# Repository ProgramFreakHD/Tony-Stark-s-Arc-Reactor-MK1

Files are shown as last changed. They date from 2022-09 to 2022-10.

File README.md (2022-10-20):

# Tony Stark's Arc Reactor MK1



## Description

READ THIS!

This Arc reactor was design in Fusion 360 under the free license, The Autodesk team has stated that "non-commercial use" meaning no one is allowed to sell or manufature the Arc reactor for profit!

DO NOT SEND ME ANY MESSAGE ABOUT PERSMISSION TO USE MY DESIGN FOR COMMERCIAL USE!

I have no controll over what will happen if failed to follow the terms, I did my end of the agreement by stating the obvious, if the end user fails to follow these terms, you will be hold accountable!

If you like my work and would like to show appreciation then consider leaving a Tip. Thank you! [PaypalMe](https://www.paypal.com/paypalme/ProgramFreakHD9999)

====================================================================

Recreated Tony Stark's arc reactor from Iron Man 1 (2008) movie. Hope you enjoy it :)

## Links

[Thingiverse Repo](https://www.thingiverse.com/thing:5526410)\
[Yr3design Arc Reactor On Thingiverse](https://www.thingiverse.com/thing:2854850)

## Summary

After looking at so many designs by many people on thingiverse, I couldn't find anything worth printing, so I decided to design my own as I imagined. My design is a bit complicated and requires stady hands, accuracy and patience to make, but it was all worth it at the end. This repository includes everything you need to make your own arc reactor and a list of components you need.

## Print Settings

[Click here for the print setting.](https://github.com/ProgramFreakHD/Ark-reactor/blob/main/Configs/Print%20Settings.md)

## My Print Choice

I decided to print mine in PLA, mainly because it's cheaper and easy to print, and doesn't have a big risk of warpage if you print without a heat chamber. For my arc reactor I decided to use black, transparent & metallic gold PLA. You need transparent PLA or any other transparent filament to be able to make the glow rings, and you need gold filament to print the gold ring in the center of the arc reactor.

Take a look in infill & resolution settings chart underneath to see what parts have to be printed in what filament color.

## Infill & Resolution Settings

The infill & resolution settings I used for my arc reactor varies from parts to parts, most likely 20% infill, but for some parts it had to be 100%. I privided a chart for the print settings and resolution that I used, so that it will make it more easier for you to get you started printing.

[Click here for the infill & resolution settings.](https://github.com/ProgramFreakHD/Ark-reactor/blob/main/Configs/Infill%20%26%20Resolution%20Settings.md)

## Assembling Of Arc Reactor

To assemble the arc reactor there isn't an easy way of describing it, for some people it's a walk in the park and for some others it's mind baffling, I will tell you this, you need good level of soldiering skills, precision and accuracy to asseble it beacuse it requires you to solder near plastic parts, and if you're not careful, you will end up with melt marks in the arc reactor.

**(NOTE: SUPERGLUE OR ANY KIND OF BONDING COMPOUND ARE NOT ALLOWED DURING ASSEMBLY OF ARK REACTOR! ONLY SCREWS ARE MEANT TO BE USED DURING ASSEMBLING!)**

Check out Assembly page to get some idea on how it's assembled. [Click Here](https://github.com/ProgramFreakHD/Tony-Stark-Arc-Reactor-MK1/blob/main/Configs/Assembly.md)

## Parts List

[Click here for the parts list.](https://github.com/ProgramFreakHD/Ark-reactor/blob/main/Configs/Parts%20list.md)

## Images


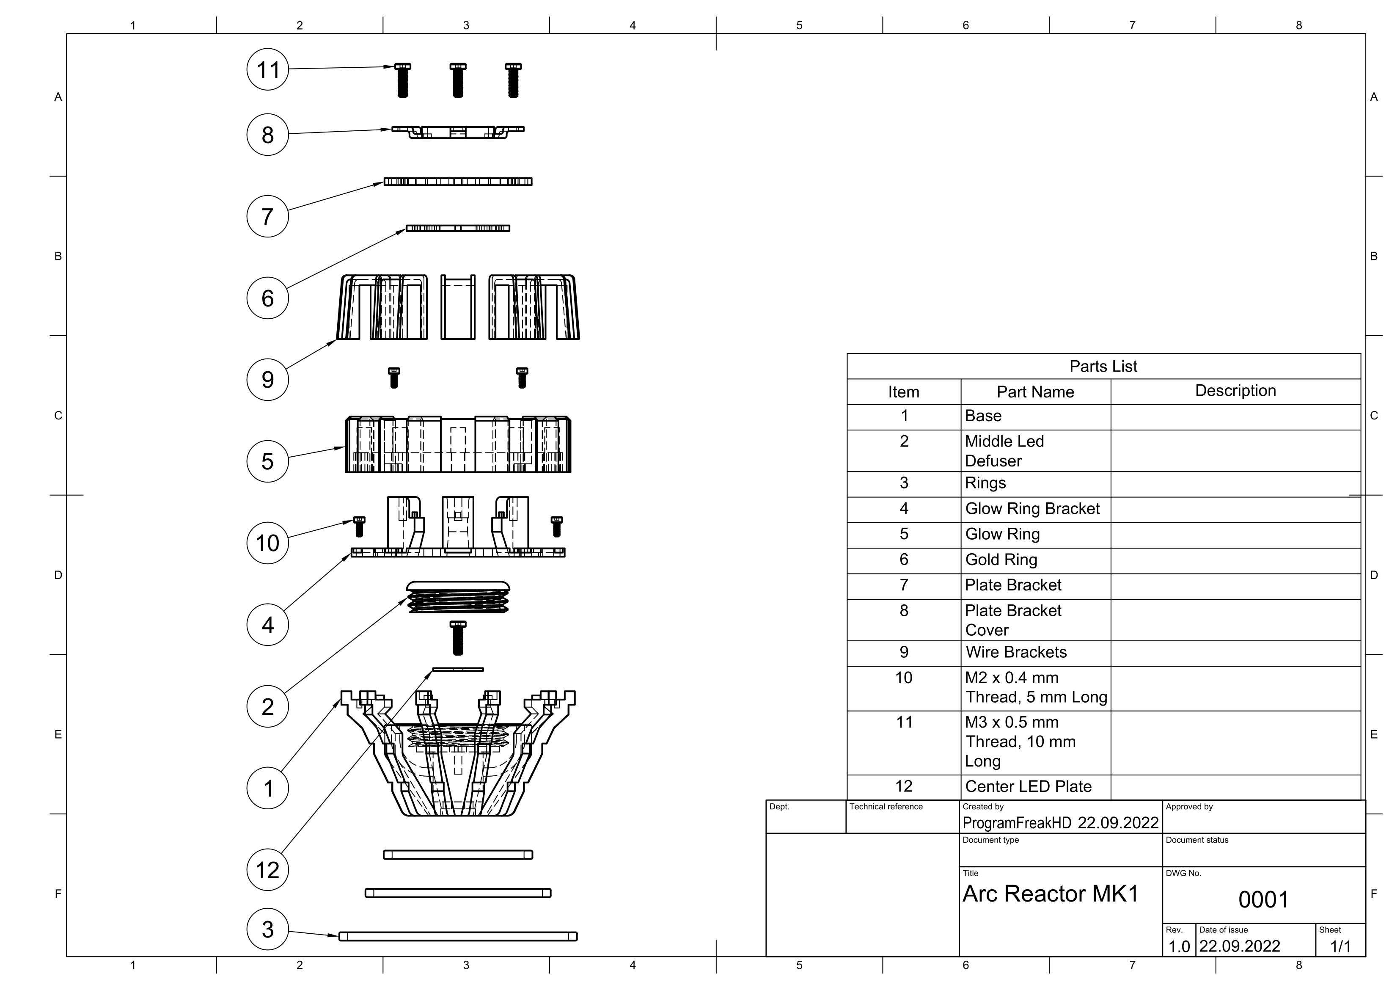
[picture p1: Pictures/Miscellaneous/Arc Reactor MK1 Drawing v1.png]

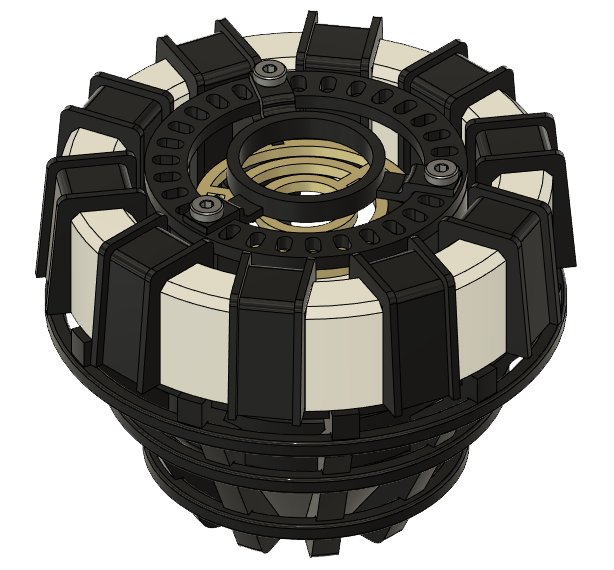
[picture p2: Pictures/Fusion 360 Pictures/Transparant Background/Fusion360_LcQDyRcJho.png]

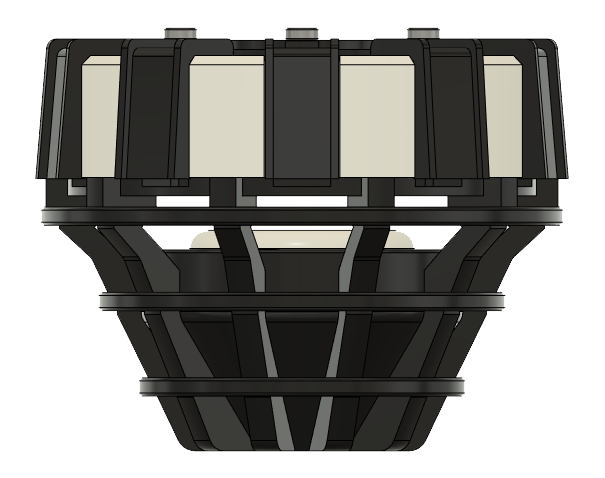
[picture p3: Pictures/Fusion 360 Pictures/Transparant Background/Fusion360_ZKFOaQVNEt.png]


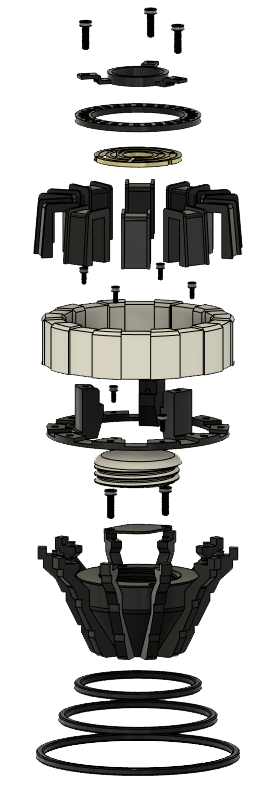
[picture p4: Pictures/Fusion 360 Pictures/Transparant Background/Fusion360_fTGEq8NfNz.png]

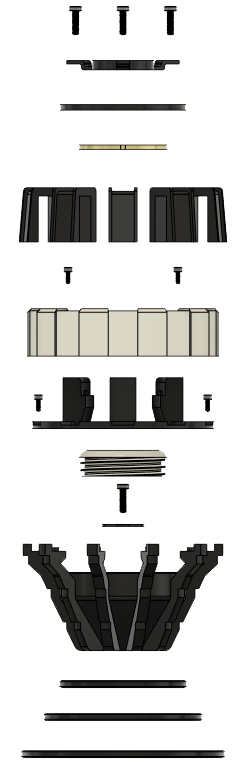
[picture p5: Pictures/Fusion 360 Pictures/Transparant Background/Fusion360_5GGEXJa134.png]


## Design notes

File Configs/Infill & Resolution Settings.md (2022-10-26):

NOTE: This chart is calibrated and designed for the Prusa I3 family printer with a standard E3D 0.4mm nozzl, The Prusa I3 family have a print resolution of minimum 0.05mm, up to a large number that is dependent on your material of choice.

Large amount of simple hobbyist own and use printers that is in Creality family, depending on your printer model and other factors, can vary your layer heigh significantly.

<table>
    <tr>
    <th>Part Names</th>
    <th>Print settings</th>
    <th>Support on build plate only</th>
    <th>Vertical shells perimeters</th>
    <th>Infill pattern</th>
    <th>Infill</th>
    <th>Brim</th>
    <th>Material</th>
    <th>Quantity</th>
  </tr>
    <tr>
    <th>Base</th>
    <th>0.15mm QUALITY</th>
    <th>Yes</th>
    <th>3</th>
    <th>Grid</th>
    <th>20%</th>
    <th>None</th>
    <th>Black PLA</th>
    <th>1</th>
  </tr>
    <tr>
    <th>Middle Led Defuser</th>
    <th>0.15mm QUALITY</th>
    <th>None</th>
    <th>3</th>
    <th>Grid</th>
    <th>100%</th>
    <th>None</th>
    <th>Transparent PLA</th>
    <th>1</th>
  </tr>
    <tr>
    <th>Small, medium and large Rings</th>
    <th>0.15mm QUALITY</th>
    <th>None</th>
    <th>3</th>
    <th>Grid</th>
    <th>100%</th>
    <th>None</th>
    <th>Black PLA</th>
    <th>1</th>
  </tr>
    <tr>
    <th>Glow Ring Bracket</th>
    <th>0.15mm QUALITY</th>
    <th>None</th>
    <th>3</th>
    <th>Grid</th>
    <th>20%</th>
    <th>None</th>
    <th>Black PLA</th>
    <th>1</th>
  </tr>
    <tr>
    <th>Glow Ring</th>
    <th>0.15mm QUALITY</th>
    <th>None</th>
    <th>3</th>
    <th>Grid</th>
    <th>100%</th>
    <th>None</th>
    <th>Transparent PLA</th>
    <th>1</th>
  </tr>
    <tr>
    <th>Gold Ring</th>
    <th>0.15mm QUALITY</th>
    <th>None</th>
    <th>3</th>
    <th>Grid</th>
    <th>100%</th>
    <th>None</th>
    <th>Gold PLA</th>
    <th>1</th>
  </tr>
    <tr>
    <th>Plate Bracket</th>
    <th>0.15mm QUALITY</th>
    <th>None</th>
    <th>3</th>
    <th>Grid</th>
    <th>100%</th>
    <th>None</th>
    <th>Black PLA</th>
    <th>1</th>
  </tr>
    <tr>
    <th>Plate Bracket Cover</th>
    <th>0.15mm QUALITY</th>
    <th>None</th>
    <th>3</th>
    <th>Grid</th>
    <th>100%</th>
    <th>None</th>
    <th>Black PLA</th>
    <th>1</th>
  </tr>
    <tr>
    <th>Wire Brackets</th>
    <th>0.30mm Draft</th>
    <th>Yes</th>
    <th>3</th>
    <th>Grid</th>
    <th>100%</th>
    <th>None</th>
    <th>Black PLA</th>
    <th>10</th>
  </tr>
    <tr>
    <th>Center Led Plate</th>
    <th>0.30mm Draft</th>
    <th>None</th>
    <th>3</th>
    <th>Grid</th>
    <th>100%</th>
    <th>None</th>
    <th>Black PLA</th>
    <th>1</th>
  </tr>
</table>

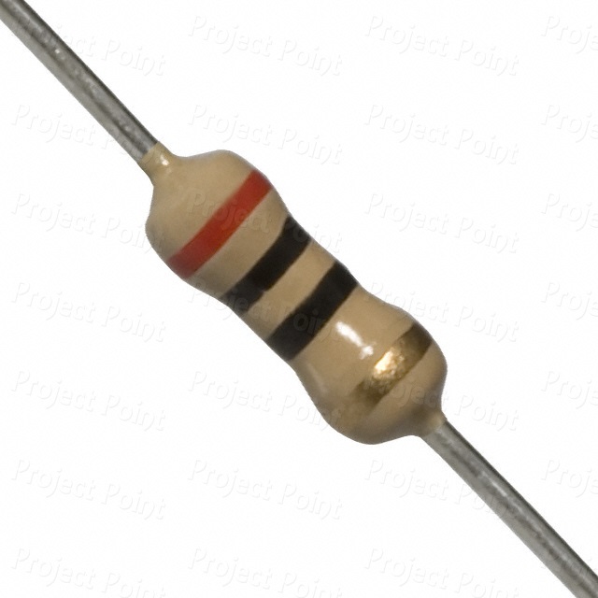
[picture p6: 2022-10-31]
Pictures/Miscellaneous/CFR-25JB-20R-1280x720.jpg

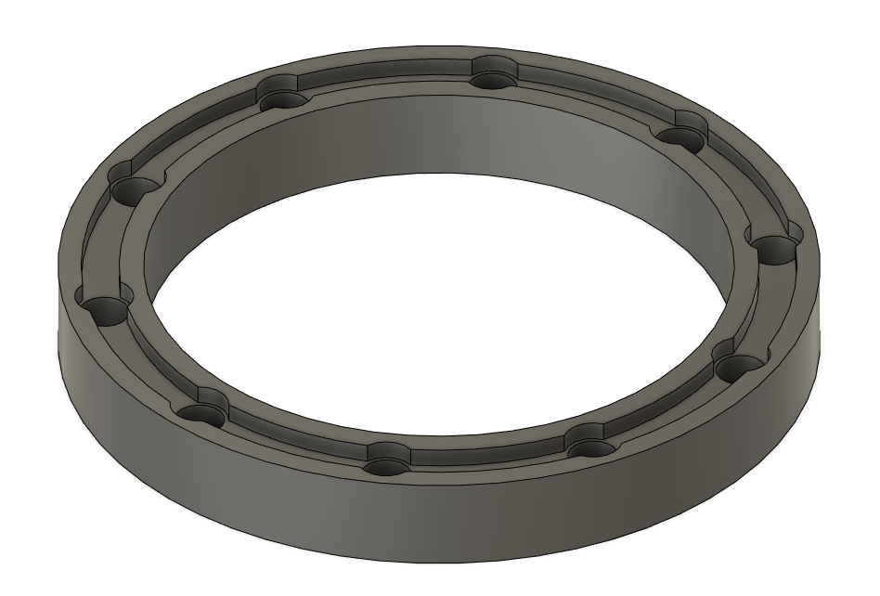
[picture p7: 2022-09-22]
Pictures/Fusion 360 Pictures/White Background/NVIDIA_Share_iF2AldNYLl.png

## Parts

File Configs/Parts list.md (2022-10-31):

## Note, I have not included any direct link for eBay and AliExpress stores, I did that intentionally because some stores do not survive for long!

# Screws

<table>
    <tr>
    <th>Screw types</th>
    <th>Quantity</th>
  </tr>
    <tr>
    <th>M2 x 5mm x 0.4mm</th>
    <th>6</th>
   <tr>
    <th>M3 x 10mm x 0.5mm</th>
    <th>5</th>
</table>

## M2 x 0.4mm Thread, 5mm Long
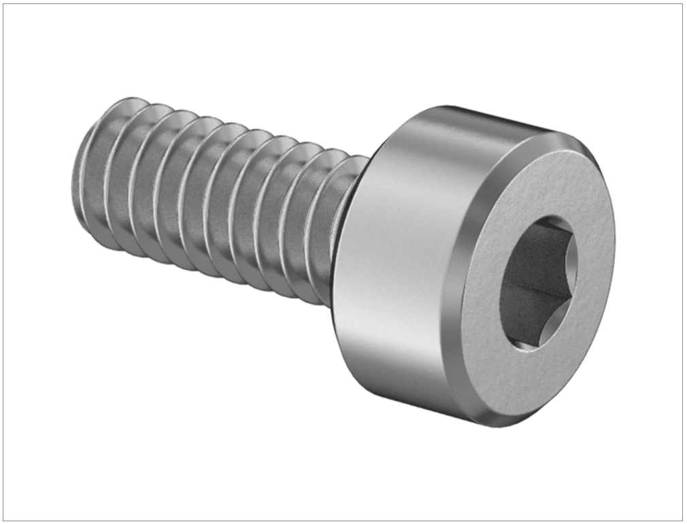
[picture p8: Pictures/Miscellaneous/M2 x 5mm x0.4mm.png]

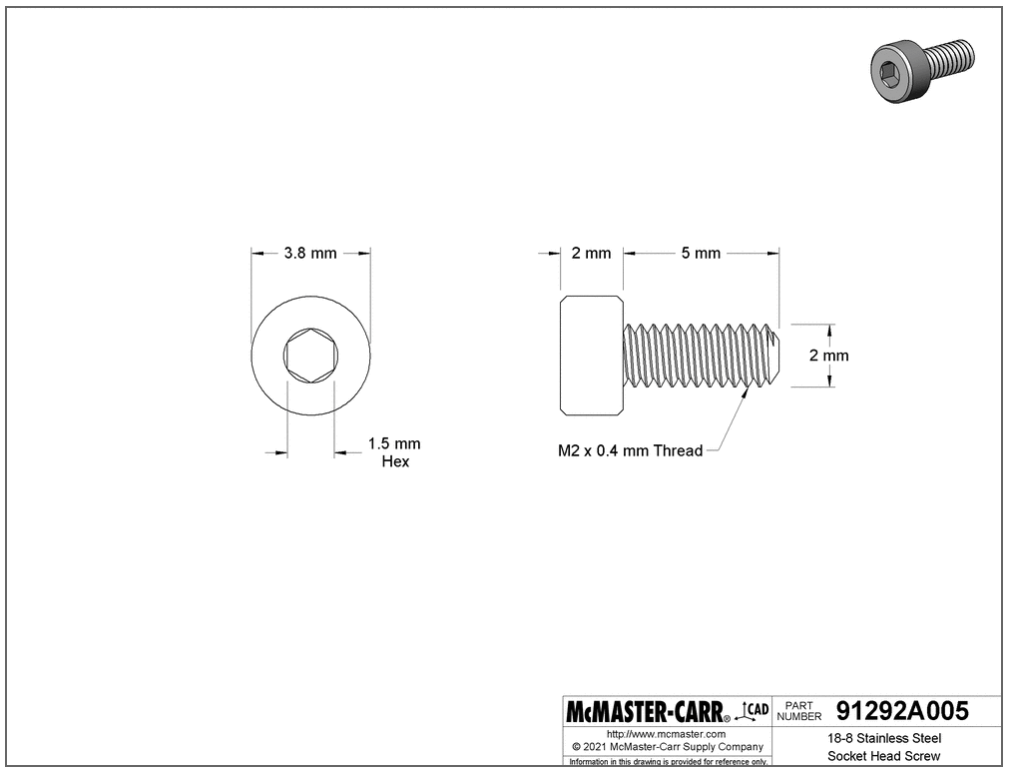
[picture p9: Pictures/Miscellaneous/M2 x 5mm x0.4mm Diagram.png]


## M3 x 0.5mm Thread, 10mm Long
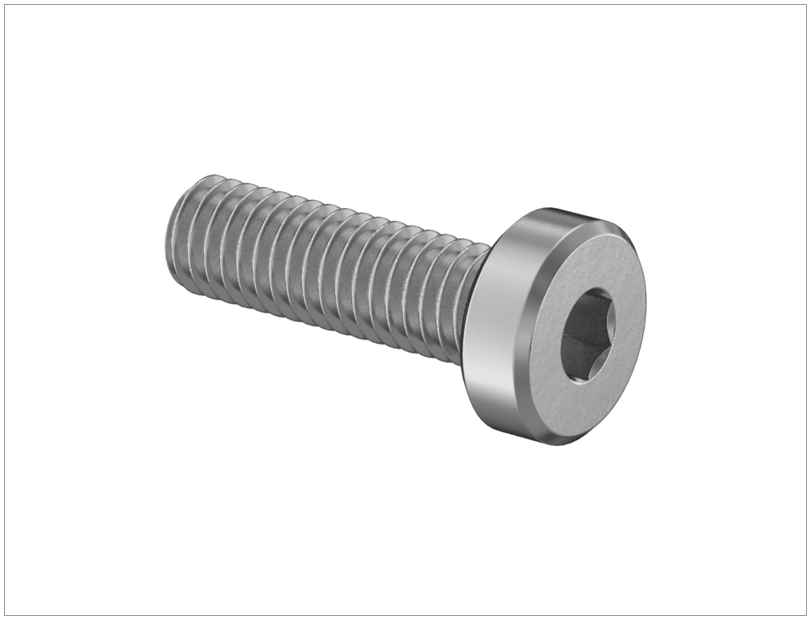
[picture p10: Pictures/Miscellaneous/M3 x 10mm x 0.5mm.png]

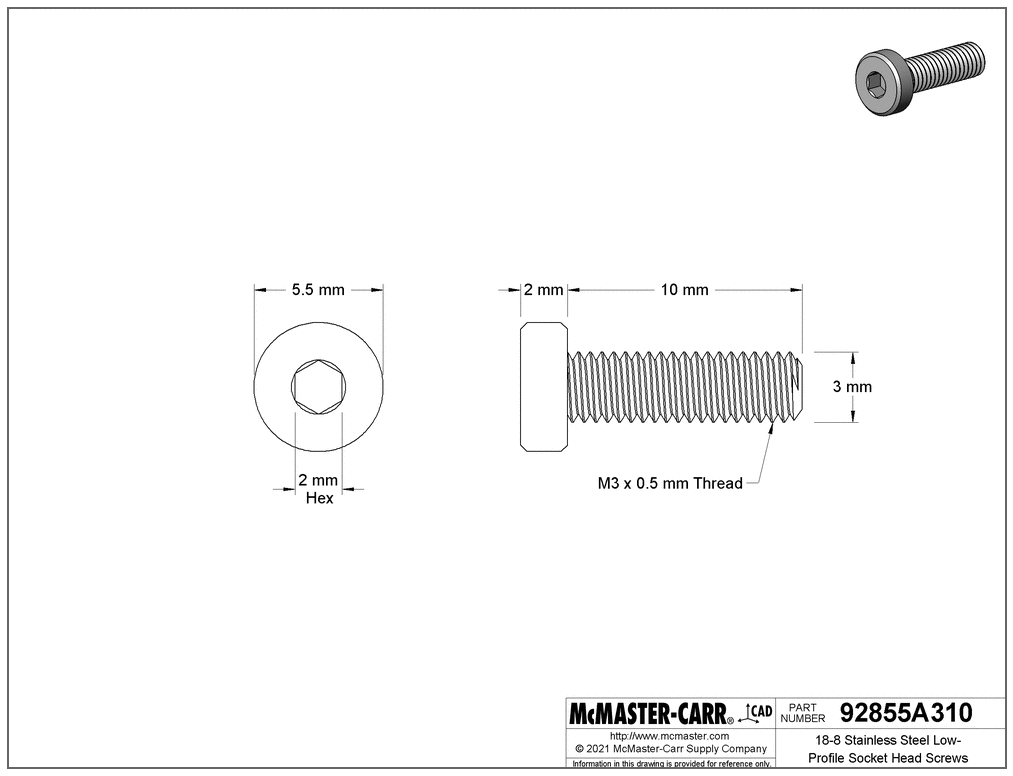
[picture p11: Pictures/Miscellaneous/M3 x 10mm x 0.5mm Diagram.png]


# Components

<table>
    <tr>
    <th>Screw types</th>
    <th>Quantity</th>
  </tr>
    <tr>
    <th>2.1mm x 5.5mm Female DC Jack</th>
    <th>1</th>
   <tr>
    <th>5mm White LED Diodes</th>
    <th>10</th>
   <tr>
    <th>3.3V Star PCB LED</th>
    <th>1</th>
</table>

## 2.1mm x 5.5mm Female DC Jack

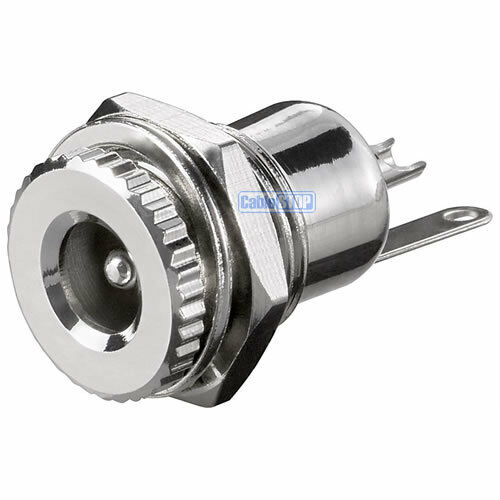
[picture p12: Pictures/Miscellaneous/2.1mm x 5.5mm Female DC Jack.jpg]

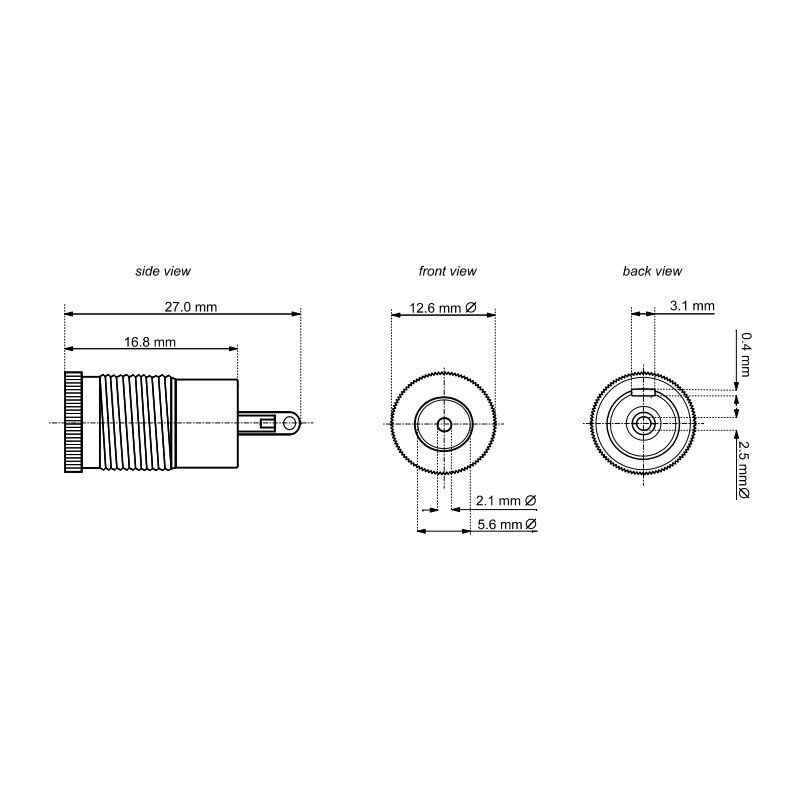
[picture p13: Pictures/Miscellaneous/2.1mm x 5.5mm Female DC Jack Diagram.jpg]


## 5mm White LED Diodes

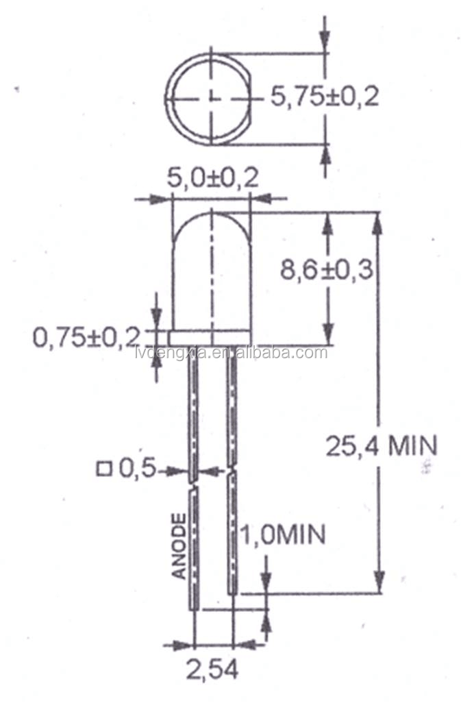
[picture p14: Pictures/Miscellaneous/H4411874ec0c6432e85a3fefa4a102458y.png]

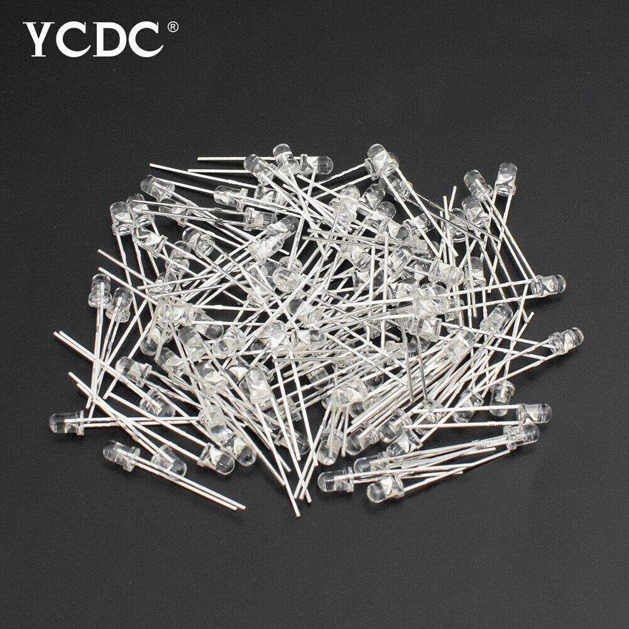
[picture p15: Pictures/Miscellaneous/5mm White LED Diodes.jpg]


## 3.3V Star PCB LED



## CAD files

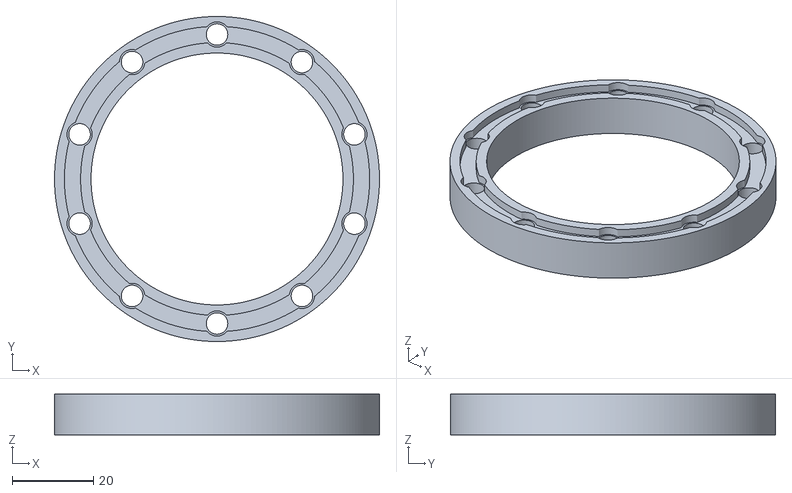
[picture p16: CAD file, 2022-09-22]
Led jig/Arc_Reactor_MK1_LED_Ring_Jig.stl
80.0 x 80.0 x 10.0

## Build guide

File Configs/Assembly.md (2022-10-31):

# LED's assembly for the glow ring.

## Soldering of the glow ring

The glow ring requires 10 white LED's soldered in a circular ring shape, The 10 LED's have to be soldered in parallel config, meaning plus is soldered to plus and minus is soldered to minus all around the ring, that way a 3.3V supply can power them all.

Now for some and many, it might be dificult to solder 10 leds in a circle by freehanding it, well, not wo worry, I have included a jig for you to print and use, it allows you to mount the LED's in a upright possiston for a better and easy solder job, and also allows you to solder them in a circular ring shape.

The jig can be found [Here](https://github.com/ProgramFreakHD/Tony-Stark-s-Arc-Reactor-MK1/tree/main/Led%20jig)!


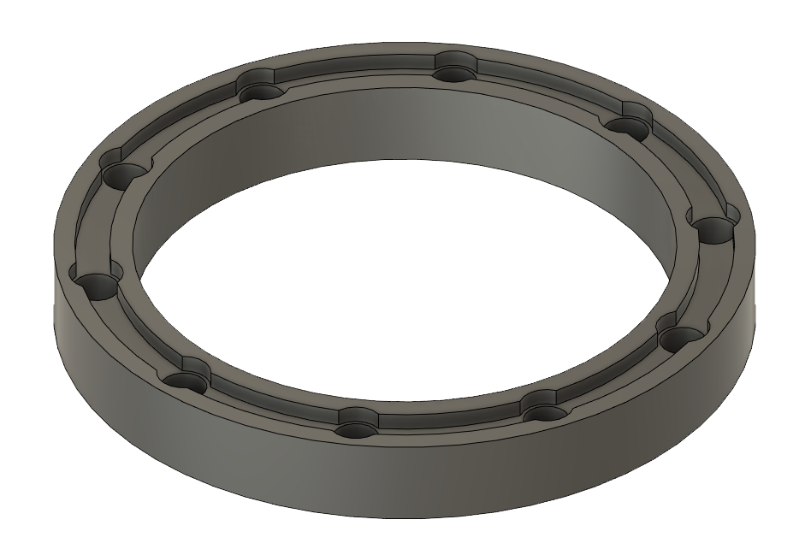
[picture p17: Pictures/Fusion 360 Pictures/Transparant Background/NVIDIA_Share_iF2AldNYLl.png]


## Center LED

The LED I used for the center of the arc reactor is a 3.3V cool white (6500k) star shaped PCB LED, nothing special with the way it's mounted, I have included a center LED plate in the thingiverse repo for you to print and mount the star led on.

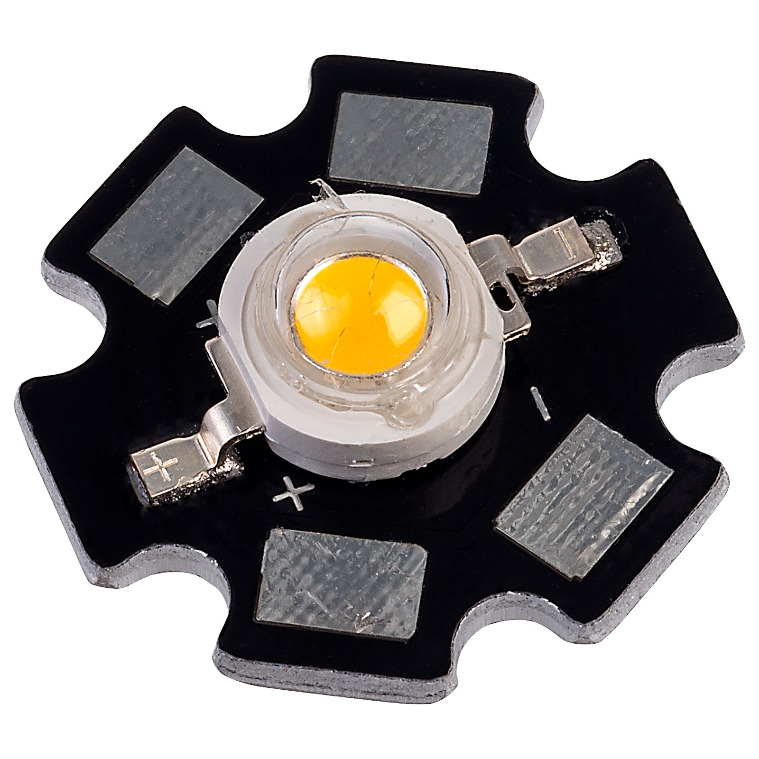
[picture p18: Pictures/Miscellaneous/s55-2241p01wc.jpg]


# Wire wrap and mounting

Insert the Led ring you just finished soldering into the transparent glow ring print, from there, you need the 10pcs wire brackets and some enameled copper wire. Don't forget to solder a pair of enameled copper wire to the led ring to provide power to the ring.

To obtain the enameled copper wire, you can find meters worth of copper wires in some old transformers, or just buy some enameled copper wire from the web.

To keep the copper wire from unwinding itself after a wrap, the best and easiest way I found is to scrape the enameling of the wire and solder the wires together for a secure fixturing.




# Power supply for the LED's

To power the LED's a 3.3V power source is required for the LED's, for my arc reactor I used 20 to 40 ohm resistor to drop down the power start with 20 ohms resistor and work yourself upwards, you can use a 3.3v powered led as a referance point as to what it sould look like, also make sure you test out the resistor on a spare led so you don't accidentally fry the main arc reactor LEDs.

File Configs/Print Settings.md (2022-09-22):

<table>
  <tr>
    <th>Printer brand</th>
    <th>Prusa</th>
  </tr>
    <tr>
    <th>Printer</th>
    <th>I3 MK3S</th>
  </tr>
    <tr>
    <th>Rafts</th>
    <th>No</th>
  </tr>
    <tr>
    <th>Supports</th>
    <th>Yes</th>
  </tr>
    <tr>
    <th>Resolution</th>
    <th>Read the description</th>
  </tr>
    <tr>
    <th>Infill</th>
    <th>Read the description</th>
  </tr>
   <tr>
   <th>Filament brand</th>
   <th>Your choice</th>
  </tr>
    <tr>
    <th>Filament color</th>
    <th>Black, Transparent & Metallic Gold</th>
  </tr>
    <tr>
    <th>Filament material</th>
    <th>PLA</th>
  </tr>
</table>

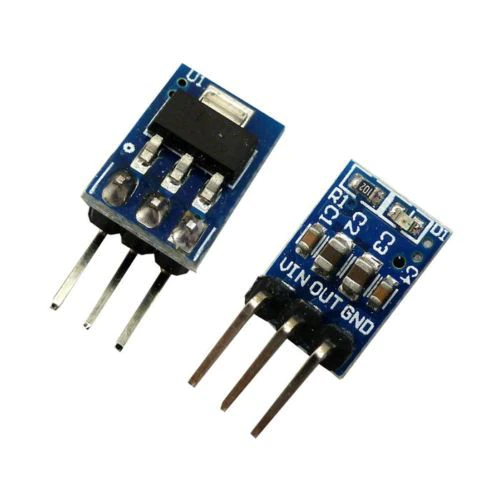
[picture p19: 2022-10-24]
Pictures/Miscellaneous/1PCS-DC-5V-to-3-3V-Step-Down-Power-Supply-Module-AMS1117-3-3-LDO-800MA.jpg
